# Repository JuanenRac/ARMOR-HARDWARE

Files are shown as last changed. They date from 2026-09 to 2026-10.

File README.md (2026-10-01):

<p align="center">
  ARMOR-HARDWARE banner
</p>

# 🧱 ARMOR-HARDWARE

<p align="center">
  🇺🇸 <b>English</b> |
  <a href="README_spa.md">🇪🇸 Español</a> |
  <a href="README_fra.md">🇫🇷 Français</a> |
  <a href="README_ita.md">🇮🇹 Italiano</a> |
  <a href="README_deu.md">🇩🇪 Deutsch</a> |
  <a href="README_zho.md">🇨🇳 简体中文</a> |
  <a href="README_jpn.md">🇯🇵 日本語</a>
</p>

### Enclosures, electronics and the bench acceptance matrix

<p align="center">
  
  
  
  
</p>

---

**Honesty check - what runs today:** The enclosure is a **printable mechanical starting point, not an IP, RF or thermal rating.** Nothing has been measured on a prototype; every row of the [bench acceptance matrix](docs/BENCH_ACCEPTANCE.md) is *not tested*.

---

## 🎯 Overview

* **The real design is `CAD/CARCASA_SENSORES.scad`** (with STL, 3MF and AMF exports): a 90-degree corner base with a visor, roof and floor, retaining steps, a sliding 2 mm front cover and side flaps, all driven by named parameters. `scad/node_enclosure.scad` is only a placeholder box.
* **Reserved volumes** for three radar modules, the ESP32-S3-ETH-PoE board, the sensor window, a cable gland, the PoE magnetics and the PTC heater. No metallic, conductive or carbon-loaded material in front of a 24 GHz aperture without measured attenuation.
* **Bench acceptance matrix:** the radio, environment, power, network and camera checks with a method and a proposed pass criterion each, and a camera compatibility table to fill in.
* Before fabrication, record exact board outlines, connectors, screw positions, antenna keep-outs, the thermal path and the ingress target ([design inputs](docs/DESIGN_INPUTS.md)).

## 📂 Repository Structure

```text
ARMOR-HARDWARE/
├── CAD/     CARCASA_SENSORES.scad (+ stl, 3mf, amf)
├── scad/    node_enclosure.scad (placeholder)
├── EDA/     KiCad (empty)
└── docs/    DESIGN_INPUTS, VALIDATION, BENCH_ACCEPTANCE
```

## 🛠️ Development Environment

```powershell
openscad -o build/CARCASA_SENSORES.stl CAD/CARCASA_SENSORES.scad
```

See the [validation boundary](docs/VALIDATION.md). The intended hardware licence is CERN-OHL-S-2.0; add its full text before releasing the designs.

## 🔗 Related Projects

**A.R.M.O.R.** (Autonomous Radar & Multimodal Observation Range) is a perimeter-security system made of independent repositories. Each one has its own version, its own tests and its own README; this is the family:

* **[ARMOR-COMMON](https://github.com/JuanenRac/ARMOR-COMMON)** - Message contracts, validators, conformance vectors and generated types
* **[ARMOR-RADAR](https://github.com/JuanenRac/ARMOR-RADAR)** - Field-node firmware for ESP32-S3 with three radars and its own web panel
* **[ARMOR-SOLAR](https://github.com/JuanenRac/ARMOR-SOLAR)** - Solar inverter and battery protocols and the messages of a gateway node
* **[ARMOR-ELECTRICAL](https://github.com/JuanenRac/ARMOR-ELECTRICAL)** - Electrical node: meters, the message of the network's readings and the rules for switching
* **[ARMOR-HMI](https://github.com/JuanenRac/ARMOR-HMI)** - Touch panel: the state of the system on a wall screen, arming and acknowledging, and the home of the voice assistant
* **[ARMOR-NETWORK](https://github.com/JuanenRac/ARMOR-NETWORK)** - The local network: its devices, the internet and what changes
* **[ARMOR-SERVER](https://github.com/JuanenRac/ARMOR-SERVER)** - Central coordinator: telemetry, alarms, devices, solar readings and cameras
* **[ARMOR-STUDIO](https://github.com/JuanenRac/ARMOR-STUDIO)** - Web console: cameras, radar, alarms, solar energy and the 2D/3D site designer
* **[ARMOR-ANDROID-CONTROL](https://github.com/JuanenRac/ARMOR-ANDROID-CONTROL)** - Android operator client with a live 2D/3D radar
* **[ARMOR-SERVER-AI](https://github.com/JuanenRac/ARMOR-SERVER-AI)** - Visual inference policy that explains its decisions and never actuates
* **[ARMOR-VOICE-AI](https://github.com/JuanenRac/ARMOR-VOICE-AI)** - Offline voice intents with a confirmation that cannot be forged
* **ARMOR-HARDWARE** (this repository) - Enclosures, electronics and the bench acceptance matrix
* **[ARMOR-DEVOPS](https://github.com/JuanenRac/ARMOR-DEVOPS)** - Deployment, the CM5 test bench, backup and TLS
* **[ARMOR-SIMULATOR](https://github.com/JuanenRac/ARMOR-SIMULATOR)** - Offline telemetry simulator with repeatable faults
* **[ARMOR-UPDATER](https://github.com/JuanenRac/ARMOR-UPDATER)** - Detects, installs and updates the ecosystem's own repositories
* **[ARMOR-DOCS](https://github.com/JuanenRac/ARMOR-DOCS)** - Architecture, security baseline and the capability matrix

## 📚 Documentation & Community

Where to read more:

* [Capability matrix: what is proven and what is not](https://github.com/JuanenRac/ARMOR-DOCS/blob/main/docs/CAPABILITY_MATRIX.md)
* [Project catalogue: versions and how the repositories depend on each other](https://github.com/JuanenRac/ARMOR-DOCS/blob/main/docs/PROJECT_CATALOG.md)
* [Changelog of this repository](CHANGELOG.md)
* [License (GPL-3.0-or-later)](LICENSE)
* Questions, ideas and reports: electrohobby3d@gmail.com

## 👤 AUTHOR

**JuanenRac (Electro Hobby 3D)** · electrohobby3d@gmail.com

## 📜 LICENSE

GPL-3.0-or-later - see [LICENSE](LICENSE).

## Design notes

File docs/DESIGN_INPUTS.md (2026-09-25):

# Design inputs and open decisions

The outdoor node design must reserve independent volumes for three radar modules,
the ESP32-S3-ETH-PoE controller, sensor window, cable gland, PoE magnetics and
PTC heater. Do not place a metallic, conductive or carbon-loaded material in
front of a 24 GHz radar aperture without measured attenuation data.

Before fabrication, record exact board outlines, connectors, screw locations,
antenna keep-outs, thermal path and ingress target. The current CAD remains a
mechanical concept, not manufacturing evidence.

## The HLK-LD2450, from its manual

Facts taken from the Hi-Link *HLK-LD2450 Instruction manual* V1.00 (2023-05-10); they are the
manufacturer's statements, not measurements of this project.

| Item | Manual |
|---|---|
| Size | 15 mm x 44 mm, pin or socket interface (UART, 5 V, GND) |
| Supply | 5 V, source able to give more than 200 mA; 120 mA average, so three modules draw about 0.6 W |
| Logic | 3.3 V I/O, UART 256000 baud, 8N1 |
| Range and angle | 6 m maximum, azimuth plus or minus 60 degrees, pitch plus or minus 35 degrees, three targets, 10 Hz |
| Band | 24 GHz to 24.25 GHz, FMCW |
| Ambient temperature | -40 to 85 degrees C |
| Mounting | Wall mounting, height 1.5 m to 2 m recommended; antenna facing the area, open and unobstructed; fixed firmly (shaking degrades detection) |
| Back of the module | The antenna's back lobe can see movement behind the module; a metal shield or back plate reduces it |
| Several 24 GHz radars | Do not point them at each other; keep them as far apart as possible |
| Cover | No metal or conductive material or coating; smooth, flat and of uniform thickness, parallel to the antenna |

### Cover guidance in the manual, applied to this enclosure

* Distance from the antenna to the inner face of the cover: 1 or 1.5 wavelengths, that is **12.4 mm or 18.6 mm** at
  24.125 GHz, tolerance plus or minus 1.2 mm.
* Thickness: about half a wavelength **in the material** (plus or minus 20 %); for an ABS-like plastic
  (relative permittivity about 2.5) that is about **3.9 mm**. If that is not possible, use a low-permittivity
  material at **one eighth of a wavelength or thinner**, about 1 mm for that same plastic.
* The CAD front cover is `tapa_grosor = 2` mm. For a permittivity near 2.5 that is close to a *quarter* of a
  wavelength in the material, which is neither of the two recommended cases and, for a plain slab, where
  reflection is greatest. This is arithmetic from the manual's formula, not a measurement, and the real
  permittivity of the printed ASA or PETG is unknown: measure it (see [BENCH_ACCEPTANCE](BENCH_ACCEPTANCE.md))
  before printing the final cover, and consider about 1 mm or about 3.9 mm.
* Check the antenna-to-cover distance in the CAD against 12.4 mm or 18.6 mm; it has not been checked.

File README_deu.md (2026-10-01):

<p align="center">
  ARMOR-HARDWARE banner
</p>

# 🧱 ARMOR-HARDWARE

<p align="center">
  <a href="README.md">🇺🇸 English</a> |
  <a href="README_spa.md">🇪🇸 Español</a> |
  <a href="README_fra.md">🇫🇷 Français</a> |
  <a href="README_ita.md">🇮🇹 Italiano</a> |
  🇩🇪 <b>Deutsch</b> |
  <a href="README_zho.md">🇨🇳 简体中文</a> |
  <a href="README_jpn.md">🇯🇵 日本語</a>
</p>

### Gehäuse, Elektronik und die Abnahmematrix am Prüfstand

<p align="center">
  
  
  
  
</p>

---

**Ehrlichkeitsprüfung - was heute läuft:** Das Gehäuse ist ein **druckbarer mechanischer Ausgangspunkt, keine IP-, HF- oder Thermik-Zertifizierung.** Nichts wurde an einem Prototyp gemessen; jede Zeile der [Abnahmematrix am Prüfstand](docs/BENCH_ACCEPTANCE.md) ist *nicht getestet*.

---

## 🎯 Überblick

* **Das echte Design ist `CAD/CARCASA_SENSORES.scad`** (mit STL-, 3MF- und AMF-Exporten): eine 90-Grad-Eckbasis mit Blende, Dach und Boden, Halte-Stufen, einer verschiebbaren 2-mm-Frontabdeckung und Seitenklappen, alles über benannte Parameter gesteuert. `scad/node_enclosure.scad` ist nur eine Platzhalterbox.
* **Reservierte Volumen** für drei Radarmodule, die Platine ESP32-S3-ETH-PoE, das Sensorfenster, eine Kabelverschraubung, die PoE-Magnetics und die PTC-Heizung. Kein metallisches, leitfähiges oder kohlenstoffgefülltes Material vor einer 24-GHz-Öffnung ohne gemessene Dämpfung.
* **Abnahmematrix am Prüfstand:** die Prüfungen für Funk, Umgebung, Strom, Netz und Kamera, jeweils mit Methode und vorgeschlagenem Bestehenskriterium, und eine auszufüllende Kamera-Kompatibilitätstabelle.
* Vor der Fertigung genaue Platinenumrisse, Steckverbinder, Schraubenpositionen, Antennen-Freihaltezonen, den Wärmepfad und das Schutzziel festhalten ([Entwurfseingaben](docs/DESIGN_INPUTS.md)).

## 📂 Struktur des Repositorys

```text
ARMOR-HARDWARE/
├── CAD/     CARCASA_SENSORES.scad (+ stl, 3mf, amf)
├── scad/    node_enclosure.scad (placeholder)
├── EDA/     KiCad (empty)
└── docs/    DESIGN_INPUTS, VALIDATION, BENCH_ACCEPTANCE
```

## 🛠️ Entwicklungsumgebung

```powershell
openscad -o build/CARCASA_SENSORES.stl CAD/CARCASA_SENSORES.scad
```

Siehe die [Validierungsgrenze](docs/VALIDATION.md). Die vorgesehene Hardwarelizenz ist CERN-OHL-S-2.0; den vollen Text vor der Veröffentlichung der Entwürfe hinzufügen.

## 🔗 Verwandte Projekte

**A.R.M.O.R.** (Autonomous Radar & Multimodal Observation Range) ist ein Perimeter-Sicherheitssystem aus unabhängigen Repositorys. Jedes hat eine eigene Version, eigene Tests und ein eigenes README; hier ist die Familie:

* **[ARMOR-COMMON](https://github.com/JuanenRac/ARMOR-COMMON)** - Nachrichtenverträge, Validierer, Konformitätsvektoren und generierte Typen
* **[ARMOR-RADAR](https://github.com/JuanenRac/ARMOR-RADAR)** - Feldknoten-Firmware für ESP32-S3 mit drei Radaren und eigenem Web-Panel
* **[ARMOR-SOLAR](https://github.com/JuanenRac/ARMOR-SOLAR)** - Protokolle für Solar-Wechselrichter und -Batterien und die Nachrichten eines Gateway-Knotens
* **[ARMOR-ELECTRICAL](https://github.com/JuanenRac/ARMOR-ELECTRICAL)** - Elektroknoten: Zähler, die Nachricht der Netzmesswerte und die Regeln fürs Schalten
* **[ARMOR-HMI](https://github.com/JuanenRac/ARMOR-HMI)** - Touch-Panel: der Systemzustand auf einem Wandbildschirm, Scharf- und Quittieren sowie das Zuhause des Sprachassistenten
* **[ARMOR-NETWORK](https://github.com/JuanenRac/ARMOR-NETWORK)** - Das lokale Netzwerk: seine Geräte, das Internet und was sich ändert
* **[ARMOR-SERVER](https://github.com/JuanenRac/ARMOR-SERVER)** - Zentraler Koordinator: Telemetrie, Alarme, Geräte, Solarmesswerte und Kameras
* **[ARMOR-STUDIO](https://github.com/JuanenRac/ARMOR-STUDIO)** - Web-Konsole: Kameras, Radar, Alarme, Solarenergie und 2D/3D-Standortdesigner
* **[ARMOR-ANDROID-CONTROL](https://github.com/JuanenRac/ARMOR-ANDROID-CONTROL)** - Android-Bedienclient mit Live-Radar in 2D/3D
* **[ARMOR-SERVER-AI](https://github.com/JuanenRac/ARMOR-SERVER-AI)** - Visuelle Inferenzrichtlinie, die ihre Entscheidungen erklärt und nie handelt
* **[ARMOR-VOICE-AI](https://github.com/JuanenRac/ARMOR-VOICE-AI)** - Offline-Sprachabsichten mit einer nicht fälschbaren Bestätigung
* **ARMOR-HARDWARE** (dieses Repository) - Gehäuse, Elektronik und die Abnahmematrix am Prüfstand
* **[ARMOR-DEVOPS](https://github.com/JuanenRac/ARMOR-DEVOPS)** - Bereitstellung, CM5-Prüfstand, Backup und TLS
* **[ARMOR-SIMULATOR](https://github.com/JuanenRac/ARMOR-SIMULATOR)** - Offline-Telemetriesimulator mit wiederholbaren Fehlern
* **[ARMOR-UPDATER](https://github.com/JuanenRac/ARMOR-UPDATER)** - Erkennt, installiert und aktualisiert die eigenen Repositories des Ökosystems
* **[ARMOR-DOCS](https://github.com/JuanenRac/ARMOR-DOCS)** - Architektur, Sicherheitsgrundlage und die Fähigkeitsmatrix

## 📚 Dokumentation und Community

Hier gibt es mehr zu lesen:

* [Fähigkeitsmatrix: was belegt ist und was nicht](https://github.com/JuanenRac/ARMOR-DOCS/blob/main/docs/CAPABILITY_MATRIX.md)
* [Projektkatalog: Versionen und wie die Repositorys voneinander abhängen](https://github.com/JuanenRac/ARMOR-DOCS/blob/main/docs/PROJECT_CATALOG.md)
* [Änderungsverlauf dieses Repositorys](CHANGELOG.md)
* [Lizenz (GPL-3.0-or-later)](LICENSE)
* Fragen, Ideen und Meldungen: electrohobby3d@gmail.com

## 👤 AUTOR

**JuanenRac (Electro Hobby 3D)** · electrohobby3d@gmail.com

## 📜 LIZENZ

GPL-3.0-or-later - siehe [LICENSE](LICENSE).

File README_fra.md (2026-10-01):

<p align="center">
  ARMOR-HARDWARE banner
</p>

# 🧱 ARMOR-HARDWARE

<p align="center">
  <a href="README.md">🇺🇸 English</a> |
  <a href="README_spa.md">🇪🇸 Español</a> |
  🇫🇷 <b>Français</b> |
  <a href="README_ita.md">🇮🇹 Italiano</a> |
  <a href="README_deu.md">🇩🇪 Deutsch</a> |
  <a href="README_zho.md">🇨🇳 简体中文</a> |
  <a href="README_jpn.md">🇯🇵 日本語</a>
</p>

### Boîtiers, électronique et matrice d'acceptation sur banc

<p align="center">
  
  
  
  
</p>

---

**Vérification d'honnêteté - ce qui fonctionne aujourd'hui:** Le boîtier est un **point de départ mécanique imprimable, pas une certification IP, RF ou thermique.** Rien n'a été mesuré sur un prototype ; chaque ligne de la [matrice d'acceptation sur banc](docs/BENCH_ACCEPTANCE.md) est *non testée*.

---

## 🎯 Présentation

* **Le vrai design est `CAD/CARCASA_SENSORES.scad`** (avec exports STL, 3MF et AMF) : une base d'angle à 90 degrés avec visière, toit et fond, des gradins de retenue, un couvercle frontal coulissant de 2 mm et des rabats latéraux, le tout piloté par des paramètres nommés. `scad/node_enclosure.scad` n'est qu'une boîte provisoire.
* **Volumes réservés** pour trois modules radar, la carte ESP32-S3-ETH-PoE, la fenêtre du capteur, un presse-étoupe, les magnétiques PoE et le réchauffeur PTC. Aucun matériau métallique, conducteur ou chargé de carbone devant une ouverture 24 GHz sans atténuation mesurée.
* **Matrice d'acceptation sur banc :** les contrôles radio, environnement, alimentation, réseau et caméra, chacun avec une méthode et un critère de réussite proposé, et un tableau de compatibilité des caméras à remplir.
* Avant la fabrication, consigner les contours exacts des cartes, les connecteurs, la position des vis, les zones d'exclusion d'antenne, le chemin thermique et l'objectif d'étanchéité ([données de conception](docs/DESIGN_INPUTS.md)).

## 📂 Structure du dépôt

```text
ARMOR-HARDWARE/
├── CAD/     CARCASA_SENSORES.scad (+ stl, 3mf, amf)
├── scad/    node_enclosure.scad (placeholder)
├── EDA/     KiCad (empty)
└── docs/    DESIGN_INPUTS, VALIDATION, BENCH_ACCEPTANCE
```

## 🛠️ Environnement de développement

```powershell
openscad -o build/CARCASA_SENSORES.stl CAD/CARCASA_SENSORES.scad
```

Voir la [frontière de validation](docs/VALIDATION.md). La licence matérielle prévue est CERN-OHL-S-2.0 ; ajoutez son texte complet avant de publier les designs.

## 🔗 Projets liés

**A.R.M.O.R.** (Autonomous Radar & Multimodal Observation Range) est un système de sécurité périmétrique composé de dépôts indépendants. Chacun a sa propre version, ses propres tests et son propre README ; voici la famille :

* **[ARMOR-COMMON](https://github.com/JuanenRac/ARMOR-COMMON)** - Contrats de messages, validateurs, vecteurs de conformité et types générés
* **[ARMOR-RADAR](https://github.com/JuanenRac/ARMOR-RADAR)** - Firmware du nœud de terrain pour ESP32-S3 avec trois radars et son propre panneau web
* **[ARMOR-SOLAR](https://github.com/JuanenRac/ARMOR-SOLAR)** - Protocoles des onduleurs et batteries solaires et messages d'un nœud passerelle
* **[ARMOR-ELECTRICAL](https://github.com/JuanenRac/ARMOR-ELECTRICAL)** - Nœud électrique : compteurs, le message des mesures du réseau et les règles de commutation
* **[ARMOR-HMI](https://github.com/JuanenRac/ARMOR-HMI)** - Panneau tactile : l'état du système sur un écran mural, armer et acquitter, et la maison de l'assistant vocal
* **[ARMOR-NETWORK](https://github.com/JuanenRac/ARMOR-NETWORK)** - Le réseau local : ses appareils, internet et ce qui change
* **[ARMOR-SERVER](https://github.com/JuanenRac/ARMOR-SERVER)** - Coordinateur central : télémétrie, alarmes, appareils, relevés solaires et caméras
* **[ARMOR-STUDIO](https://github.com/JuanenRac/ARMOR-STUDIO)** - Console web : caméras, radar, alarmes, énergie solaire et concepteur de site 2D/3D
* **[ARMOR-ANDROID-CONTROL](https://github.com/JuanenRac/ARMOR-ANDROID-CONTROL)** - Client Android de l'opérateur avec radar 2D/3D en direct
* **[ARMOR-SERVER-AI](https://github.com/JuanenRac/ARMOR-SERVER-AI)** - Politique d'inférence visuelle qui explique ses décisions et n'agit jamais
* **[ARMOR-VOICE-AI](https://github.com/JuanenRac/ARMOR-VOICE-AI)** - Intentions vocales hors ligne avec une confirmation impossible à falsifier
* **ARMOR-HARDWARE** (ce dépôt) - Boîtiers, électronique et matrice d'acceptation sur banc
* **[ARMOR-DEVOPS](https://github.com/JuanenRac/ARMOR-DEVOPS)** - Déploiement, banc d'essai CM5, sauvegarde et TLS
* **[ARMOR-SIMULATOR](https://github.com/JuanenRac/ARMOR-SIMULATOR)** - Simulateur de télémétrie hors ligne avec des pannes reproductibles
* **[ARMOR-UPDATER](https://github.com/JuanenRac/ARMOR-UPDATER)** - Détecte, installe et met à jour les propres dépôts de l'écosystème
* **[ARMOR-DOCS](https://github.com/JuanenRac/ARMOR-DOCS)** - Architecture, base de sécurité et matrice des capacités

## 📚 Documentation et communauté

Pour en savoir plus :

* [Matrice des capacités : ce qui est prouvé et ce qui ne l'est pas](https://github.com/JuanenRac/ARMOR-DOCS/blob/main/docs/CAPABILITY_MATRIX.md)
* [Catalogue des projets : versions et dépendances entre les dépôts](https://github.com/JuanenRac/ARMOR-DOCS/blob/main/docs/PROJECT_CATALOG.md)
* [Historique des modifications de ce dépôt](CHANGELOG.md)
* [Licence (GPL-3.0-or-later)](LICENSE)
* Questions, idées et rapports : electrohobby3d@gmail.com

## 👤 AUTEUR

**JuanenRac (Electro Hobby 3D)** · electrohobby3d@gmail.com

## 📜 LICENCE

GPL-3.0-or-later - voir [LICENSE](LICENSE).

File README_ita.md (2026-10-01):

<p align="center">
  ARMOR-HARDWARE banner
</p>

# 🧱 ARMOR-HARDWARE

<p align="center">
  <a href="README.md">🇺🇸 English</a> |
  <a href="README_spa.md">🇪🇸 Español</a> |
  <a href="README_fra.md">🇫🇷 Français</a> |
  🇮🇹 <b>Italiano</b> |
  <a href="README_deu.md">🇩🇪 Deutsch</a> |
  <a href="README_zho.md">🇨🇳 简体中文</a> |
  <a href="README_jpn.md">🇯🇵 日本語</a>
</p>

### Contenitori, elettronica e matrice di accettazione da banco

<p align="center">
  
  
  
  
</p>

---

**Controllo di onestà - cosa funziona oggi:** Il contenitore è un **punto di partenza meccanico stampabile, non una certificazione IP, RF o termica.** Nulla è stato misurato su un prototipo; ogni riga della [matrice di accettazione da banco](docs/BENCH_ACCEPTANCE.md) è *non testata*.

---

## 🎯 Panoramica

* **Il vero progetto è `CAD/CARCASA_SENSORES.scad`** (con esportazioni STL, 3MF e AMF): una base d'angolo a 90 gradi con visiera, tetto e fondo, gradini di ritegno, un coperchio frontale scorrevole da 2 mm e alette laterali, tutto guidato da parametri con nome. `scad/node_enclosure.scad` è solo una scatola provvisoria.
* **Volumi riservati** per tre moduli radar, la scheda ESP32-S3-ETH-PoE, la finestra del sensore, un passacavo, la magnetica PoE e il riscaldatore PTC. Nessun materiale metallico, conduttivo o caricato di carbonio davanti a un'apertura a 24 GHz senza attenuazione misurata.
* **Matrice di accettazione da banco:** i controlli di radio, ambiente, alimentazione, rete e telecamera, ciascuno con un metodo e un criterio di superamento proposto, e una tabella di compatibilità delle telecamere da compilare.
* Prima della fabbricazione, registrare i contorni esatti delle schede, i connettori, la posizione delle viti, le aree di esclusione delle antenne, il percorso termico e l'obiettivo di tenuta ([dati di progetto](docs/DESIGN_INPUTS.md)).

## 📂 Struttura del repository

```text
ARMOR-HARDWARE/
├── CAD/     CARCASA_SENSORES.scad (+ stl, 3mf, amf)
├── scad/    node_enclosure.scad (placeholder)
├── EDA/     KiCad (empty)
└── docs/    DESIGN_INPUTS, VALIDATION, BENCH_ACCEPTANCE
```

## 🛠️ Ambiente di sviluppo

```powershell
openscad -o build/CARCASA_SENSORES.stl CAD/CARCASA_SENSORES.scad
```

Vedi il [confine di validazione](docs/VALIDATION.md). La licenza hardware prevista è CERN-OHL-S-2.0; aggiungi il testo completo prima di pubblicare i progetti.

## 🔗 Progetti correlati

**A.R.M.O.R.** (Autonomous Radar & Multimodal Observation Range) è un sistema di sicurezza perimetrale fatto di repository indipendenti. Ognuno ha la propria versione, i propri test e il proprio README; ecco la famiglia:

* **[ARMOR-COMMON](https://github.com/JuanenRac/ARMOR-COMMON)** - Contratti dei messaggi, validatori, vettori di conformità e tipi generati
* **[ARMOR-RADAR](https://github.com/JuanenRac/ARMOR-RADAR)** - Firmware del nodo di campo per ESP32-S3 con tre radar e un proprio pannello web
* **[ARMOR-SOLAR](https://github.com/JuanenRac/ARMOR-SOLAR)** - Protocolli di inverter e batterie solari e messaggi di un nodo gateway
* **[ARMOR-ELECTRICAL](https://github.com/JuanenRac/ARMOR-ELECTRICAL)** - Nodo elettrico: contatori, il messaggio delle letture della rete e le regole di manovra
* **[ARMOR-HMI](https://github.com/JuanenRac/ARMOR-HMI)** - Pannello touch: lo stato del sistema su uno schermo a parete, attivare e riconoscere gli allarmi, e la casa dell'assistente vocale
* **[ARMOR-NETWORK](https://github.com/JuanenRac/ARMOR-NETWORK)** - La rete locale: i suoi dispositivi, internet e ciò che cambia
* **[ARMOR-SERVER](https://github.com/JuanenRac/ARMOR-SERVER)** - Coordinatore centrale: telemetria, allarmi, dispositivi, letture solari e telecamere
* **[ARMOR-STUDIO](https://github.com/JuanenRac/ARMOR-STUDIO)** - Console web: telecamere, radar, allarmi, energia solare e progettista del sito 2D/3D
* **[ARMOR-ANDROID-CONTROL](https://github.com/JuanenRac/ARMOR-ANDROID-CONTROL)** - Client Android dell'operatore con radar 2D/3D in tempo reale
* **[ARMOR-SERVER-AI](https://github.com/JuanenRac/ARMOR-SERVER-AI)** - Politica di inferenza visiva che spiega le sue decisioni e non agisce mai
* **[ARMOR-VOICE-AI](https://github.com/JuanenRac/ARMOR-VOICE-AI)** - Intenti vocali offline con una conferma impossibile da falsificare
* **ARMOR-HARDWARE** (questo repository) - Contenitori, elettronica e matrice di accettazione da banco
* **[ARMOR-DEVOPS](https://github.com/JuanenRac/ARMOR-DEVOPS)** - Distribuzione, banco di prova CM5, backup e TLS
* **[ARMOR-SIMULATOR](https://github.com/JuanenRac/ARMOR-SIMULATOR)** - Simulatore di telemetria offline con guasti ripetibili
* **[ARMOR-UPDATER](https://github.com/JuanenRac/ARMOR-UPDATER)** - Rileva, installa e aggiorna i repository stessi dell'ecosistema
* **[ARMOR-DOCS](https://github.com/JuanenRac/ARMOR-DOCS)** - Architettura, base di sicurezza e matrice delle capacità

## 📚 Documentazione e comunità

Dove leggere di più:

* [Matrice delle capacità: cosa è provato e cosa no](https://github.com/JuanenRac/ARMOR-DOCS/blob/main/docs/CAPABILITY_MATRIX.md)
* [Catalogo dei progetti: versioni e dipendenze tra i repository](https://github.com/JuanenRac/ARMOR-DOCS/blob/main/docs/PROJECT_CATALOG.md)
* [Cronologia delle modifiche di questo repository](CHANGELOG.md)
* [Licenza (GPL-3.0-or-later)](LICENSE)
* Domande, idee e segnalazioni: electrohobby3d@gmail.com

## 👤 AUTORE

**JuanenRac (Electro Hobby 3D)** · electrohobby3d@gmail.com

## 📜 LICENZA

GPL-3.0-or-later - vedi [LICENSE](LICENSE).

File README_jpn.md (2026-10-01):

<p align="center">
  ARMOR-HARDWARE banner
</p>

# 🧱 ARMOR-HARDWARE

<p align="center">
  <a href="README.md">🇺🇸 English</a> |
  <a href="README_spa.md">🇪🇸 Español</a> |
  <a href="README_fra.md">🇫🇷 Français</a> |
  <a href="README_ita.md">🇮🇹 Italiano</a> |
  <a href="README_deu.md">🇩🇪 Deutsch</a> |
  <a href="README_zho.md">🇨🇳 简体中文</a> |
  🇯🇵 <b>日本語</b>
</p>

### 筐体、電子部品、ベンチ受け入れマトリクス

<p align="center">
  
  
  
  
</p>

---

**正直さのチェック - 今日動いているもの:** 筐体は**印刷可能な機械的な出発点であり、IP、RF、熱の認証ではありません。** 試作品では何も測定していません。[ベンチ受け入れマトリクス](docs/BENCH_ACCEPTANCE.md)のすべての行は*未テスト*です。

---

## 🎯 概要

* **本当の設計は `CAD/CARCASA_SENSORES.scad`**（STL、3MF、AMF のエクスポート付き）：ひさし、屋根、床を備えた 90 度のコーナーベース、保持用の段、2 mm のスライド式フロントカバーとサイドフラップ。すべて名前付きパラメーターで制御されます。`scad/node_enclosure.scad` は仮の箱にすぎません。
* **予約された空間：** レーダーモジュール 3 基、ESP32-S3-ETH-PoE ボード、センサー窓、ケーブルグランド、PoE マグネティクス、PTC ヒーター。減衰を測定していない限り、24 GHz の開口の前に金属、導電性、カーボン入りの材料を置かないこと。
* **ベンチ受け入れマトリクス：** 無線、環境、電源、ネットワーク、カメラの各チェックに、方法と提案する合格基準を付け、記入するカメラ互換性表も用意しています。
* 製造の前に、ボードの正確な外形、コネクター、ネジ位置、アンテナの禁止領域、熱経路、防塵防水の目標を記録すること（[設計入力](docs/DESIGN_INPUTS.md)）。

## 📂 リポジトリの構成

```text
ARMOR-HARDWARE/
├── CAD/     CARCASA_SENSORES.scad (+ stl, 3mf, amf)
├── scad/    node_enclosure.scad (placeholder)
├── EDA/     KiCad (empty)
└── docs/    DESIGN_INPUTS, VALIDATION, BENCH_ACCEPTANCE
```

## 🛠️ 開発環境

```powershell
openscad -o build/CARCASA_SENSORES.stl CAD/CARCASA_SENSORES.scad
```

[検証の境界](docs/VALIDATION.md)を参照。想定するハードウェアライセンスは CERN-OHL-S-2.0 です。設計を公開する前にその全文を追加してください。

## 🔗 関連プロジェクト

**A.R.M.O.R.**（Autonomous Radar & Multimodal Observation Range）は、独立したリポジトリで構成される周辺警備システムです。それぞれに独自のバージョン、テスト、README があります。ファミリーは次のとおりです：

* **[ARMOR-COMMON](https://github.com/JuanenRac/ARMOR-COMMON)** - メッセージ契約、検証器、適合性ベクトル、生成された型
* **[ARMOR-RADAR](https://github.com/JuanenRac/ARMOR-RADAR)** - ESP32-S3 用フィールドノードのファームウェア。レーダー 3 基と独自の Web パネル付き
* **[ARMOR-SOLAR](https://github.com/JuanenRac/ARMOR-SOLAR)** - 太陽光インバーターとバッテリーのプロトコル、およびゲートウェイノードのメッセージ
* **[ARMOR-ELECTRICAL](https://github.com/JuanenRac/ARMOR-ELECTRICAL)** - 電気ノード：電力量計、電力網の計測メッセージ、開閉のルール
* **[ARMOR-HMI](https://github.com/JuanenRac/ARMOR-HMI)** - タッチパネル：壁面ディスプレイでのシステム状態表示、警戒・確認操作、音声アシスタントの拠点
* **[ARMOR-NETWORK](https://github.com/JuanenRac/ARMOR-NETWORK)** - ローカルネットワーク：機器、インターネット、そして変化
* **[ARMOR-SERVER](https://github.com/JuanenRac/ARMOR-SERVER)** - 中央コーディネーター：テレメトリ、アラーム、デバイス、太陽光の測定値、カメラ
* **[ARMOR-STUDIO](https://github.com/JuanenRac/ARMOR-STUDIO)** - Web コンソール：カメラ、レーダー、アラーム、太陽光発電、2D/3D サイト設計
* **[ARMOR-ANDROID-CONTROL](https://github.com/JuanenRac/ARMOR-ANDROID-CONTROL)** - リアルタイム 2D/3D レーダー付きの Android オペレータークライアント
* **[ARMOR-SERVER-AI](https://github.com/JuanenRac/ARMOR-SERVER-AI)** - 判断を説明し、決して動作しない視覚推論ポリシー
* **[ARMOR-VOICE-AI](https://github.com/JuanenRac/ARMOR-VOICE-AI)** - 偽造できない確認を備えたオフライン音声インテント
* **ARMOR-HARDWARE** (このリポジトリ) - 筐体、電子部品、ベンチ受け入れマトリクス
* **[ARMOR-DEVOPS](https://github.com/JuanenRac/ARMOR-DEVOPS)** - デプロイ、CM5 テストベンチ、バックアップ、TLS
* **[ARMOR-SIMULATOR](https://github.com/JuanenRac/ARMOR-SIMULATOR)** - 再現可能な故障を備えたオフラインのテレメトリシミュレーター
* **[ARMOR-UPDATER](https://github.com/JuanenRac/ARMOR-UPDATER)** - エコシステム自身のリポジトリを検出し、インストールし、更新する
* **[ARMOR-DOCS](https://github.com/JuanenRac/ARMOR-DOCS)** - アーキテクチャ、セキュリティ基準、機能マトリクス

## 📚 ドキュメントとコミュニティ

詳しくは：

* [機能マトリクス：実証済みのものとそうでないもの](https://github.com/JuanenRac/ARMOR-DOCS/blob/main/docs/CAPABILITY_MATRIX.md)
* [プロジェクト一覧：バージョンとリポジトリ間の依存関係](https://github.com/JuanenRac/ARMOR-DOCS/blob/main/docs/PROJECT_CATALOG.md)
* [このリポジトリの変更履歴](CHANGELOG.md)
* [ライセンス（GPL-3.0-or-later）](LICENSE)
* 質問・提案・報告：electrohobby3d@gmail.com

## 👤 作者

**JuanenRac (Electro Hobby 3D)** · electrohobby3d@gmail.com

## 📜 ライセンス

GPL-3.0-or-later - [LICENSE](LICENSE) を参照。

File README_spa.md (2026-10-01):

<p align="center">
  ARMOR-HARDWARE banner
</p>

# 🧱 ARMOR-HARDWARE

<p align="center">
  <a href="README.md">🇺🇸 English</a> |
  🇪🇸 <b>Español</b> |
  <a href="README_fra.md">🇫🇷 Français</a> |
  <a href="README_ita.md">🇮🇹 Italiano</a> |
  <a href="README_deu.md">🇩🇪 Deutsch</a> |
  <a href="README_zho.md">🇨🇳 简体中文</a> |
  <a href="README_jpn.md">🇯🇵 日本語</a>
</p>

### Carcasas, electrónica y la matriz de aceptación de banco

<p align="center">
  
  
  
  
</p>

---

**Comprobación de honestidad - qué funciona hoy:** La carcasa es un **punto de partida mecánico imprimible, no una clasificación IP, RF ni térmica.** No se ha medido nada en un prototipo; cada fila de la [matriz de aceptación de banco](docs/BENCH_ACCEPTANCE.md) está *sin probar*.

---

## 🎯 Descripción general

* **El diseño real es `CAD/CARCASA_SENSORES.scad`** (con exportaciones STL, 3MF y AMF): una base de esquina de 90 grados con visera, techo y suelo, escalones de retención, una tapa frontal deslizante de 2 mm y solapas laterales, todo gobernado por parámetros con nombre. `scad/node_enclosure.scad` es solo una caja de ejemplo.
* **Volúmenes reservados** para tres módulos de radar, la placa ESP32-S3-ETH-PoE, la ventana del sensor, un prensaestopas, la magnética PoE y el calefactor PTC. Ningún material metálico, conductor o cargado de carbono delante de una apertura de 24 GHz sin atenuación medida.
* **Matriz de aceptación de banco:** las comprobaciones de radio, entorno, alimentación, red y cámaras con un método y un criterio propuesto cada una, y una tabla de compatibilidad de cámaras por rellenar.
* Antes de fabricar, registrar contornos exactos de placas, conectores, posición de tornillos, zonas libres de antena, el camino térmico y el objetivo de estanqueidad ([entradas de diseño](docs/DESIGN_INPUTS.md)).

## 📂 Estructura del repositorio

```text
ARMOR-HARDWARE/
├── CAD/     CARCASA_SENSORES.scad (+ stl, 3mf, amf)
├── scad/    node_enclosure.scad (ejemplo)
├── EDA/     KiCad (vacío)
└── docs/    DESIGN_INPUTS, VALIDATION, BENCH_ACCEPTANCE
```

## 🛠️ Entorno de desarrollo

```powershell
openscad -o build/CARCASA_SENSORES.stl CAD/CARCASA_SENSORES.scad
```

Véase el [límite de validación](docs/VALIDATION.md). La licencia de hardware prevista es CERN-OHL-S-2.0; añade su texto completo antes de publicar los diseños.

## 🔗 Proyectos relacionados

**A.R.M.O.R.** (Autonomous Radar & Multimodal Observation Range) es un sistema de seguridad perimetral hecho de repositorios independientes. Cada uno tiene su propia versión, sus propias pruebas y su propio README; esta es la familia:

* **[ARMOR-COMMON](https://github.com/JuanenRac/ARMOR-COMMON)** - Contratos de mensajes, validadores, vectores de conformidad y tipos generados
* **[ARMOR-RADAR](https://github.com/JuanenRac/ARMOR-RADAR)** - Firmware del nodo de campo para ESP32-S3 con tres radares y su propio panel web
* **[ARMOR-SOLAR](https://github.com/JuanenRac/ARMOR-SOLAR)** - Protocolos de inversores y baterías solares y los mensajes de un nodo pasarela
* **[ARMOR-ELECTRICAL](https://github.com/JuanenRac/ARMOR-ELECTRICAL)** - Nodo eléctrico: contadores, el mensaje de las lecturas de la red y las reglas para maniobrar
* **[ARMOR-HMI](https://github.com/JuanenRac/ARMOR-HMI)** - Panel táctil: el estado del sistema en una pantalla de pared, armar y reconocer alarmas, y el hogar del asistente de voz
* **[ARMOR-NETWORK](https://github.com/JuanenRac/ARMOR-NETWORK)** - La red local: sus dispositivos, internet y lo que cambia
* **[ARMOR-SERVER](https://github.com/JuanenRac/ARMOR-SERVER)** - Coordinador central: telemetría, alarmas, dispositivos, lecturas solares y cámaras
* **[ARMOR-STUDIO](https://github.com/JuanenRac/ARMOR-STUDIO)** - Consola web: cámaras, radar, alarmas, energía solar y el diseñador de sitio 2D/3D
* **[ARMOR-ANDROID-CONTROL](https://github.com/JuanenRac/ARMOR-ANDROID-CONTROL)** - Cliente Android del operador con radar 2D/3D en vivo
* **[ARMOR-SERVER-AI](https://github.com/JuanenRac/ARMOR-SERVER-AI)** - Política de inferencia visual que explica sus decisiones y nunca actúa
* **[ARMOR-VOICE-AI](https://github.com/JuanenRac/ARMOR-VOICE-AI)** - Intenciones de voz sin conexión con una confirmación imposible de falsificar
* **ARMOR-HARDWARE** (este repositorio) - Cajas, electrónica y la matriz de aceptación en banco
* **[ARMOR-DEVOPS](https://github.com/JuanenRac/ARMOR-DEVOPS)** - Despliegue, el banco de pruebas de la CM5, copias de seguridad y TLS
* **[ARMOR-SIMULATOR](https://github.com/JuanenRac/ARMOR-SIMULATOR)** - Simulador de telemetría sin conexión con fallos repetibles
* **[ARMOR-UPDATER](https://github.com/JuanenRac/ARMOR-UPDATER)** - Detecta, instala y actualiza los propios repositorios del ecosistema
* **[ARMOR-DOCS](https://github.com/JuanenRac/ARMOR-DOCS)** - Arquitectura, base de seguridad y la matriz de capacidades

## 📚 Documentación y comunidad

Dónde leer más:

* [Matriz de capacidades: qué está probado y qué no](https://github.com/JuanenRac/ARMOR-DOCS/blob/main/docs/CAPABILITY_MATRIX.md)
* [Catálogo de proyectos: versiones y cómo dependen unos de otros](https://github.com/JuanenRac/ARMOR-DOCS/blob/main/docs/PROJECT_CATALOG.md)
* [Historial de cambios de este repositorio](CHANGELOG.md)
* [Licencia (GPL-3.0-or-later)](LICENSE)
* Preguntas, ideas e informes: electrohobby3d@gmail.com

## 👤 AUTOR

**JuanenRac (Electro Hobby 3D)** · electrohobby3d@gmail.com

## 📜 LICENCIA

GPL-3.0-or-later - véase [LICENSE](LICENSE).

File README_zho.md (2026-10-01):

<p align="center">
  ARMOR-HARDWARE banner
</p>

# 🧱 ARMOR-HARDWARE

<p align="center">
  <a href="README.md">🇺🇸 English</a> |
  <a href="README_spa.md">🇪🇸 Español</a> |
  <a href="README_fra.md">🇫🇷 Français</a> |
  <a href="README_ita.md">🇮🇹 Italiano</a> |
  <a href="README_deu.md">🇩🇪 Deutsch</a> |
  🇨🇳 <b>简体中文</b> |
  <a href="README_jpn.md">🇯🇵 日本語</a>
</p>

### 外壳、电子器件和台架验收矩阵

<p align="center">
  
  
  
  
</p>

---

**诚实性检查 - 今天真正能运行的部分:** 外壳是一个**可打印的机械起点，不是 IP、射频或热学认证。** 没有在原型上测量过任何东西；[台架验收矩阵](docs/BENCH_ACCEPTANCE.md)的每一行都是*未测试*。

---

## 🎯 概述

* **真正的设计是 `CAD/CARCASA_SENSORES.scad`**（附 STL、3MF 和 AMF 导出）：带遮光檐、顶部和底板的 90 度拐角底座、固位台阶、2 mm 滑动前盖和侧翼，全部由命名参数驱动。`scad/node_enclosure.scad` 只是占位盒。
* **预留空间**：三个雷达模块、ESP32-S3-ETH-PoE 开发板、传感器窗口、电缆固定头、PoE 磁性元件和 PTC 加热器。在没有实测衰减的情况下，24 GHz 窗口前不得使用金属、导电或含碳材料。
* **台架验收矩阵：** 射频、环境、电源、网络和摄像头检查，每项都有方法和建议的通过标准，另有待填写的摄像头兼容性表。
* 制造前，记录开发板的精确外形、连接器、螺丝位置、天线禁区、热路径和防护目标（[设计输入](docs/DESIGN_INPUTS.md)）。

## 📂 仓库结构

```text
ARMOR-HARDWARE/
├── CAD/     CARCASA_SENSORES.scad (+ stl, 3mf, amf)
├── scad/    node_enclosure.scad (placeholder)
├── EDA/     KiCad (empty)
└── docs/    DESIGN_INPUTS, VALIDATION, BENCH_ACCEPTANCE
```

## 🛠️ 开发环境

```powershell
openscad -o build/CARCASA_SENSORES.stl CAD/CARCASA_SENSORES.scad
```

参见[验证边界](docs/VALIDATION.md)。预期的硬件许可证是 CERN-OHL-S-2.0；发布设计前请补上其完整文本。

## 🔗 相关项目

**A.R.M.O.R.**（Autonomous Radar & Multimodal Observation Range）是由若干独立仓库组成的周界安防系统。每个仓库都有自己的版本、测试和 README；家族成员如下：

* **[ARMOR-COMMON](https://github.com/JuanenRac/ARMOR-COMMON)** - 消息契约、验证器、一致性向量和生成的类型
* **[ARMOR-RADAR](https://github.com/JuanenRac/ARMOR-RADAR)** - 适用于 ESP32-S3 的现场节点固件，带三个雷达和自带网页面板
* **[ARMOR-SOLAR](https://github.com/JuanenRac/ARMOR-SOLAR)** - 太阳能逆变器与电池的协议，以及网关节点的消息
* **[ARMOR-ELECTRICAL](https://github.com/JuanenRac/ARMOR-ELECTRICAL)** - 电气节点：电表、电网读数消息和开关规则
* **[ARMOR-HMI](https://github.com/JuanenRac/ARMOR-HMI)** - 触摸面板：墙面屏幕上的系统状态、布防与确认，以及语音助手的所在
* **[ARMOR-NETWORK](https://github.com/JuanenRac/ARMOR-NETWORK)** - 本地网络：其设备、互联网以及变化
* **[ARMOR-SERVER](https://github.com/JuanenRac/ARMOR-SERVER)** - 中央协调器：遥测、报警、设备、太阳能读数和摄像头
* **[ARMOR-STUDIO](https://github.com/JuanenRac/ARMOR-STUDIO)** - 网页控制台：摄像头、雷达、报警、太阳能和 2D/3D 场地设计器
* **[ARMOR-ANDROID-CONTROL](https://github.com/JuanenRac/ARMOR-ANDROID-CONTROL)** - 带实时 2D/3D 雷达的 Android 操作员客户端
* **[ARMOR-SERVER-AI](https://github.com/JuanenRac/ARMOR-SERVER-AI)** - 会解释决策且从不执行动作的视觉推理策略
* **[ARMOR-VOICE-AI](https://github.com/JuanenRac/ARMOR-VOICE-AI)** - 带无法伪造确认的离线语音意图
* **ARMOR-HARDWARE** (本仓库) - 外壳、电子器件和台架验收矩阵
* **[ARMOR-DEVOPS](https://github.com/JuanenRac/ARMOR-DEVOPS)** - 部署、CM5 测试台、备份与 TLS
* **[ARMOR-SIMULATOR](https://github.com/JuanenRac/ARMOR-SIMULATOR)** - 带可重复故障的离线遥测模拟器
* **[ARMOR-UPDATER](https://github.com/JuanenRac/ARMOR-UPDATER)** - 发现、安装并更新生态系统自身的仓库
* **[ARMOR-DOCS](https://github.com/JuanenRac/ARMOR-DOCS)** - 架构、安全基线和能力矩阵

## 📚 文档与社区

更多阅读：

* [能力矩阵：哪些已被证实，哪些没有](https://github.com/JuanenRac/ARMOR-DOCS/blob/main/docs/CAPABILITY_MATRIX.md)
* [项目目录：版本以及各仓库之间的依赖](https://github.com/JuanenRac/ARMOR-DOCS/blob/main/docs/PROJECT_CATALOG.md)
* [本仓库的变更记录](CHANGELOG.md)
* [许可证（GPL-3.0-or-later）](LICENSE)
* 问题、想法与反馈：electrohobby3d@gmail.com

## 👤 作者

**JuanenRac (Electro Hobby 3D)** · electrohobby3d@gmail.com

## 📜 许可证

GPL-3.0-or-later - 见 [LICENSE](LICENSE)。

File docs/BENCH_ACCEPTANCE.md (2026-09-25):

# Bench acceptance matrix

Nothing here has been measured yet. Every row starts as **not tested**. The requirements come
from the project specification; the pass criteria marked *proposed* are engineering suggestions
to be confirmed or changed by the owner before a prototype is built, and they are not results.

A row turns to **passed** only with a dated measurement record (instrument, method, value,
photo or log) stored with the prototype. A criterion that cannot be measured is rewritten until it can.

## Radio and sensing

| Item | Requirement | How to verify | Pass criterion | Status |
|---|---|---|---|---|
| 24 GHz transparency of the 1 mm radar cover (printed ASA/PETG) | The cover must not hide a person from the LD2450 | Same target at the same distances with and without the cover; compare reported range and track continuity | *Proposed:* detection range loss under 10 % and no track drops on a walking person at 3 m and 6 m | not tested |
| Cover thickness and distance | The front cover is 2 mm in the CAD, close to a quarter wavelength in an ABS-like plastic; the manual recommends about 3.9 mm or 1 mm or thinner, and 12.4 mm or 18.6 mm from the antenna to the cover | Measure the detection range and position error with covers of about 1 mm, 2 mm and 3.9 mm, and with the antenna at about 12 mm and 18 mm from the cover | *Proposed:* the chosen thickness loses the least range; record the material's real permittivity | not tested |
| Cover material | No metallic, conductive or carbon-loaded material in front of a radar aperture | Material data sheet; repeat the row above for each print material and colour | Attenuation measured for every material actually used | not tested |
| Three-sensor coverage | Three LD2450/LD2461 cover the 90° corner without a blind wedge | Walk a marked arc at 2, 4 and 6 m; record which sensor reports | Every angle covered by at least one sensor; hand-over between sensors keeps one track | not tested |
| Mounting height and back lobe | The manual recommends 1.5 m to 2 m and a metal shield behind the module | Walk behind the enclosure with and without a metal back plate | No phantom tracks from movement behind the node | not tested |
| Sensor separation | Radars do not disturb each other | Run all three, then one at a time; compare tracks | No change in a reference target's reported position beyond sensor noise | not tested |
| Ambient light window | The VEML7700 reads correctly through the translucent window | Compare against a reference lux meter from dark to full sun | *Proposed:* within 20 % across the range; day/night threshold flips at the configured lux | not tested |

## Environment

| Item | Requirement | How to verify | Pass criterion | Status |
|---|---|---|---|---|
| Ingress | Watertight corner enclosure with a peak visor | Spray test to the chosen IP target; cable gland torque per data sheet | *Target to be chosen:* no water inside after the test | not tested |
| Condensation drainage | Drainage holes let condensation out | Cycle temperature and humidity in a chamber or overnight outdoors | No standing water; window stays clear with the heater working | not tested |
| PTC surface temperature | The anti-fog heater must not damage the print or the electronics | Thermocouple on the PTC surface and on the nearest printed wall at full heater duty in a warm enclosure | *Proposed:* printed wall under 60 °C and no deformation after 8 h; well below the material's glass transition | not tested |
| Dew-point control | The heater keeps the window above the dew point | Cold-humid soak; log window temperature and dew point | Window stays more than 3 °C above the dew point while heating; heater off when dry | not tested |
| Print material | ASA or PETG survives the site | Sun and heat soak on a sample | No warp that opens a seam or shifts a sensor | not tested |

## Power and network

| Item | Requirement | How to verify | Pass criterion | Status |
|---|---|---|---|---|
| PoE budget | Node 3.8 to 5.5 W with the heater on; camera about 8 to 12 W; a 30 W PoE+ input leaves about 12.5 W margin | Inline power meter on the 48 V feed at idle, radars on, heater on, camera IR and motor active | Measured peak stays under the 30 W port limit with margin | not tested |
| PoE isolation | The PoE magnetics are isolated | Board and switch data sheets; continuity and hi-pot per the design | Isolation confirmed for the exact board used | not tested |
| Network segmentation | Field devices sit in the sensor VLAN with no internet | From a node and a camera: reach the broker, fail to reach the internet and other VLANs | Only the allowed broker, RTSP and API paths work | not tested |
| Broker identity | One identity and ACL per node | Try to read or write another node's topics with a node's credentials | Refused | not tested |
| Power loss | Central power redundancy | Pull the switch or server power with a UPS in place | Nodes report offline through the last will; the server restarts cleanly | not tested |

## Cameras

| Item | Requirement | How to verify | Pass criterion | Status |
|---|---|---|---|---|
| Stream | RTSP main and sub streams work | Discover paths from the server; view live for an hour | Stable video, no relay restarts | not tested |
| PTZ | Bounded movement over the camera's real protocol (Hi3510, PSIA or ONVIF) | Each direction, zoom and stop from Studio and the phone | Moves and stops; a fixed camera reports a real failure | not tested |
| Digest authentication | The camera accepts the server's authentication scheme | Test each camera model and firmware | Recorded per model in the compatibility table | not tested |

## Compatibility table (fill in per camera)

| Camera model and firmware | RTSP path | Auth | PTZ protocol | Night IR | Result |
|---|---|---|---|---|---|
| | | | | | not tested |

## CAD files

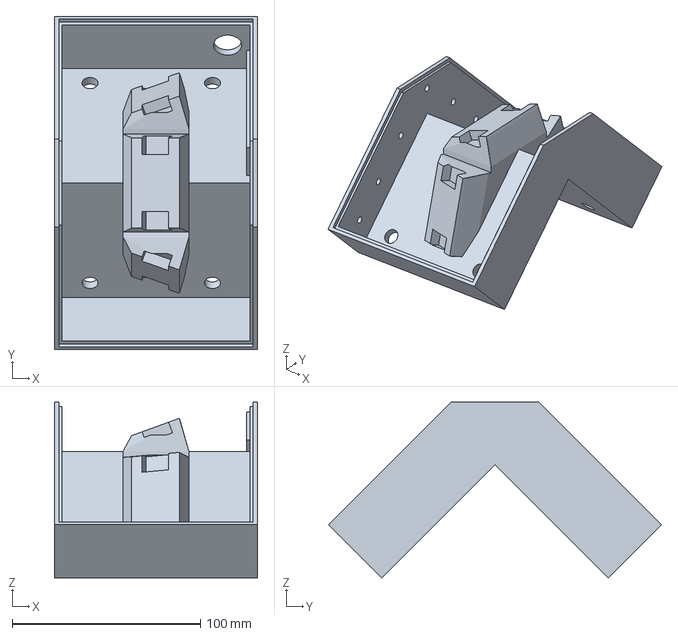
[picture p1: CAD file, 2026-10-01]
scad/node_enclosure_radar_1.3mf
108.0 x 176.8 x 93.3 mm

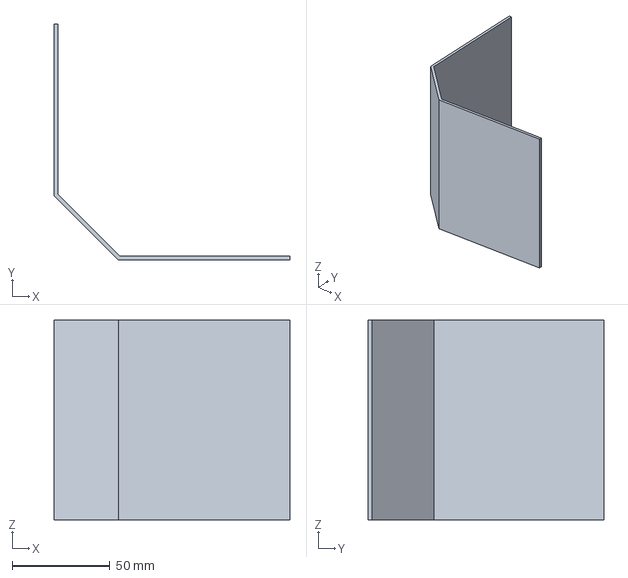
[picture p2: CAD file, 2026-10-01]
scad/node_enclosure_radar_2.3mf
121.0 x 121.0 x 102.5 mm

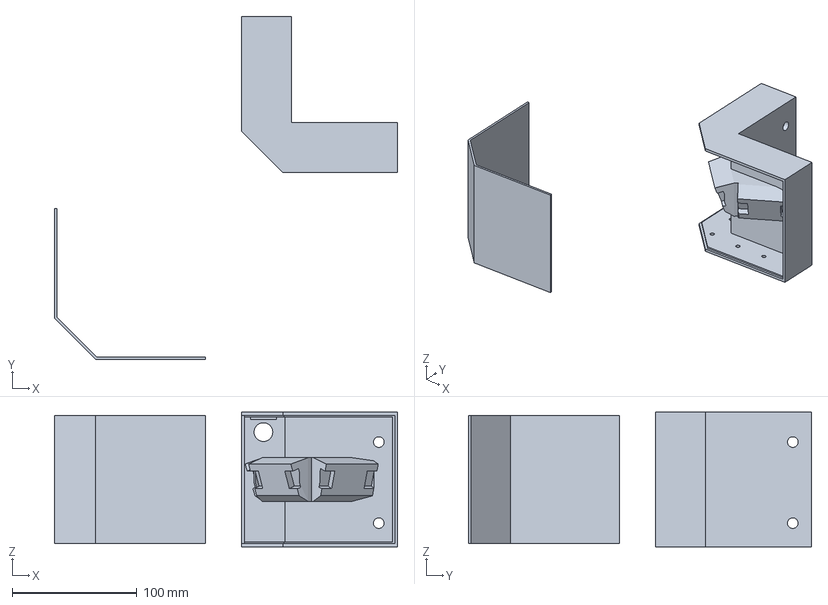
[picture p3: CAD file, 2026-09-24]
scad/node_enclosure_radar.3mf
275.0 x 275.0 x 108.0 mm

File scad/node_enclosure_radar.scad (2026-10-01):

// ==========================================================
// A.R.M.O.R - CORNER BASE WITH DYNAMICALLY LINKED SLOTS
// ==========================================================
$fn = 50;

// ==========================================================
// 1. MAIN BASE STRUCTURE (X, Y, Z)
// ==========================================================
face_length_x = 90;       // Total extension of back wall X (mm)
face_length_y = 90;       // Total extension of back wall Y (mm)
base_height_z  = 100;     // Total height of main base Z (mm)
wall_thickness  = 5;      // Thickness of L-shaped back walls (mm)

// ==========================================================
// 2. FRAME, STEPS, AND COVER PARAMETERS
// ==========================================================

// --- 2.1. CEILING AND FLOOR (Z VISORS) ---
ceiling_z_offset  = 100;  // Z start position of the ceiling (mm)
ceiling_thickness_z  = 4; // Z thickness/depth of the ceiling (mm)

floor_z_offset  = -4;     // Z start position of the floor (mm)
floor_thickness_z  = 4;   // Z thickness/depth of the floor (mm)

// --- 2.2. STEPS / OUTER RETAINING FRAMES (4 SIDES) ---
floor_step_z   = 2.5;     // Bottom tab (floor Z)
ceiling_step_z   = 2.5;   // Top tab (ceiling Z)
lateral_step_x = 0.0;     // Right lateral outer tab (overlap X)
lateral_step_y = 0.0;     // Left lateral outer tab (overlap Y)

// --- 2.3. FRONT COVER (MAIN DIMENSIONS) ---
visor_chamfer  = 33;      // Corner diagonal cut/chamfer size (mm)
cover_thickness     = 2;  // Nominal thickness of the front cover (mm)
cover_clearance_xy = 0.25;// Perimeter sliding clearance in X/Y (mm)
cover_clearance_z  = 0.25;// Vertical clearance in Z (mm)

// --- 2.4. AUTOMATICALLY LINKED SLOT CONTROL ---
// Automatically calculated based on cover_thickness + clearance:
slot_depth_x    = cover_thickness + cover_clearance_xy;  
slot_depth_y    = cover_thickness + cover_clearance_xy;  

// Penetration / Bite inside lateral flaps (mm):
slot_bite_x = 2.0;        // Cut rail depth in lateral flap X
slot_bite_y = 2.0;        // Cut rail depth in lateral flap Y

// --- 2.5. LATERAL FLAPS (X, Y) ---
flap_x_thickness  = 4;    // Total thickness of lateral flap X (mm)
flap_x_overhang_y = 35;   // Outer projection/overhang face X (mm)
flap_x_z_start = -4;      // Vertical Z start of flap X (mm)
flap_x_z_height  = 108;   // Total Z height of flap X (mm)

flap_y_thickness  = 4;    // Total thickness of lateral flap Y (mm)
flap_y_overhang_x = 35;   // Outer projection/overhang face Y (mm)
flap_y_z_start = -4;      // Vertical Z start of flap Y (mm)
flap_y_z_height  = 108;   // Total Z height of flap Y (mm)

separation_distance = 150;// Disassembly distance in view mode 0 (mm)

// ==========================================================
// 3. ELEMENT CONFIGURATION AND DRILL HOLES
// ==========================================================

// --- 3.1. WALL ANCHOR DRILL HOLES (M8) ---
screw_d = 8.5;

wallX_hole_1 = [75, -20, 15];
wallX_hole_2 = [75, -20, 80];
wallY_hole_1 = [-20, 75, 15];
wallY_hole_2 = [-20, 75, 80];

// --- 3.2. LATERAL CABLE GLAND / PASSTHROUGH ---
cable_gland_d = 15;
cable_gland_pos = [-17.5, 88, 88];
cable_gland_rot = [90, 0, 0];

// --- 3.3. TOP LEFT SOLID RECTANGLE ---
rect_length = 73;
rect_width = 21;
rect_thickness = 4;
rect_pos = [-17.5, 35, 100];
rect_rot = [0, 0, 0];

// --- 3.4. CONDENSATION DRAINAGE ---
drain_d = 4;
drain_points = [
    [20, -15, 0],
    [50, -15, 0],
    [75, -15, 0],
    [-15, 20, 0],
    [-15, 50, 0],
    [-15, 75, 0],
    [-12, -12, 0]
];

// --- 3.5. LATERAL SENSOR RECESSES ---
s1_recess_left_height = 15;  s1_recess_left_width = 10;  s1_recess_left_depth = 5;  s1_recess_left_dist = 20;
s1_recess_right_height = 15; s1_recess_right_width = 10; s1_recess_right_depth = 5; s1_recess_right_dist = 20;

s2_recess_left_height = 15;  s2_recess_left_width = 10;  s2_recess_left_depth = 5;  s2_recess_left_dist = 20;
s2_recess_right_height = 15; s2_recess_right_width = 10; s2_recess_right_depth = 5; s2_recess_right_dist = 20;

s3_recess_left_height = 15;  s3_recess_left_width = 10;  s3_recess_left_depth = 5;  s3_recess_left_dist = 20;
s3_recess_right_height = 15; s3_recess_right_width = 10; s3_recess_right_depth = 5; s3_recess_right_dist = 20;

// ==========================================================
// 4. SENSOR DIMENSIONS AND POSITIONS
// ==========================================================
sensor_width = 40;        
sensor_height = 15;         

s1_x = 45;  s1_y = -5;  s1_z = 50;  s1_azimuth = 30;   s1_tilt = 20;
s2_x = -5;  s2_y = 45;  s2_z = 50;  s2_azimuth = -120; s2_tilt = 20;
s3_x = 0;   s3_y = 0;   s3_z = 50;  s3_azimuth = -45;  s3_tilt = 20;  s3_depth = 28;

// ==========================================================
// CONSTRUCTION MODULES AND 2D/3D PROFILES
// ==========================================================

module solid_block(tilt) {
    hull() {
        translate([0, 4, 0]) 
            cube([sensor_width + 12, 8, sensor_height + 20], center=true);
        translate([0, -12, 0]) 
            rotate([tilt, 0, 0]) 
            cube([sensor_width + 8, 2, sensor_height + 12], center=true);
    }
}

module central_solid_block(tilt, depth) {
    hull() {
        translate([0, depth/2, 0]) 
            cube([sensor_width + 12, depth, sensor_height + 20], center=true);
        translate([0, -12, 0]) 
            rotate([tilt, 0, 0]) 
            cube([sensor_width + 8, 2, sensor_height + 12], center=true);
    }
}

module single_recess(width, depth, height, dist_x, tilt) {
    translate([0, -12, 0])
        rotate([tilt, 0, 0])
            translate([dist_x, -1 + depth/2, 0])
                cube([width, depth + 2, height], center=true);
}

// 2D OUTER CEILING/FLOOR PROFILE
module outer_frame_profile_2d() {
    dimension_x = -flap_x_overhang_y - lateral_step_x;
    dimension_y = -flap_y_overhang_x - lateral_step_y;
    
    polygon(points=[
        [wall_thickness, wall_thickness],
        [face_length_x, wall_thickness],
        [face_length_x, dimension_x],
        [dimension_y + visor_chamfer, dimension_x],
        [dimension_y, dimension_x + visor_chamfer],
        [dimension_y, face_length_y],
        [wall_thickness, face_length_y]
    ]);
}

// 2D COVER HOUSING CHANNEL (HOLLOW LAYER BASED ON COVER THICKNESS + CLEARANCE)
module cover_cut_profile_2d() {
    k_off_x = slot_depth_x * (sqrt(2) - 1);
    k_off_y = slot_depth_y * (sqrt(2) - 1);

    p1_out = [face_length_x - flap_x_thickness + slot_bite_x, -flap_x_overhang_y];
    p2_out = [-flap_y_overhang_x + visor_chamfer, -flap_x_overhang_y];
    p3_out = [-flap_y_overhang_x, -flap_x_overhang_y + visor_chamfer];
    p4_out = [-flap_y_overhang_x, face_length_y - flap_y_thickness + slot_bite_y];

    p4_in  = [-flap_y_overhang_x + slot_depth_y, face_length_y - flap_y_thickness + slot_bite_y];
    p3_in  = [-flap_y_overhang_x + slot_depth_y, -flap_x_overhang_y + visor_chamfer + k_off_y];
    p2_in  = [-flap_y_overhang_x + visor_chamfer + k_off_x, -flap_x_overhang_y + slot_depth_x];
    p1_in  = [face_length_x - flap_x_thickness + slot_bite_x, -flap_x_overhang_y + slot_depth_x];

    polygon(points=[p1_out, p2_out, p3_out, p4_out, p4_in, p3_in, p2_in, p1_in]);
}

// 2D FRONT COVER PROFILE (DYNAMICALLY SUPPORTS ANY THICKNESS)
module cover_profile_2d() {
    k_offset = cover_thickness * (sqrt(2) - 1);
    
    p1_out = [face_length_x - flap_x_thickness, -flap_x_overhang_y];
    p2_out = [-flap_y_overhang_x + visor_chamfer, -flap_x_overhang_y];
    p3_out = [-flap_y_overhang_x, -flap_x_overhang_y + visor_chamfer];
    p4_out = [-flap_y_overhang_x, face_length_y - flap_y_thickness];
    
    p4_in  = [-flap_y_overhang_x + cover_thickness, face_length_y - flap_y_thickness];
    p3_in  = [-flap_y_overhang_x + cover_thickness, -flap_x_overhang_y + visor_chamfer + k_offset];
    p2_in  = [-flap_y_overhang_x + visor_chamfer + k_offset, -flap_x_overhang_y + cover_thickness];
    p1_in  = [face_length_x - flap_x_thickness, -flap_x_overhang_y + cover_thickness];
    
    polygon(points=[p1_out, p2_out, p3_out, p4_out, p4_in, p3_in, p2_in, p1_in]);
}

// ==========================================================
// MAIN BASE PIECE
// ==========================================================

module outer_support() {
    dimension_x = -flap_x_overhang_y - lateral_step_x;
    dimension_y = -flap_y_overhang_x - lateral_step_y;

    cut_start_z = floor_z_offset + floor_step_z; 
    cut_end_z    = ceiling_z_offset + ceiling_thickness_z - ceiling_step_z;
    total_cut_h  = cut_end_z - cut_start_z;
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

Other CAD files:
scad/node_enclosure_radar.amf
scad/node_enclosure_radar.stl

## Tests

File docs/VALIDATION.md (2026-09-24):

# Hardware validation boundary

The enclosure model is a printable mechanical starting point, not an IP, RF or
thermal rating. Validate 24 GHz attenuation, condensation drainage, cable glands,
PoE isolation and PTC surface temperature on a real prototype before deployment.

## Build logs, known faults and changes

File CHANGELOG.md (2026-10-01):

# Changelog

All notable changes to this project are documented here.

## [0.2.3] - The enclosure moves to `scad/` as the radar enclosure

- The real design, until now `CAD/CARCASA_SENSORES.scad`, is `scad/node_enclosure_radar.scad`, with its STL, 3MF and AMF exports; its parameters and comments are now in English. The placeholder box `scad/node_enclosure.scad` and the `CAD/` folder are gone.
- Two new 3MF slicer project files, `node_enclosure_radar_1.3mf` (the base, about 125 x 125 x 108 mm) and `node_enclosure_radar_2.3mf` (the sliding cover), each ready to slice on its own. `view_mode` (0 exploded, 1 assembled, 2 the base alone, 3 the cover alone) chooses what the file draws or exports.
- The build/test step, CI's OpenSCAD guard and the manifest follow the new path (`armor_project_tool.py` re-synced from ARMOR-COMMON 0.2.7); the seven READMEs describe the new files and the real file tree (they no longer list the empty `CAD/` and `EDA/` folders, which Git never held).

## [0.2.2]

- A GitHub Actions CI baseline (`.github/workflows/ci.yml`): validates the manifest, the version, CHANGELOG.md's heading, the seven README translations' structure and its own local Markdown links, then runs this project's real build/test through `tools/armor_project_tool.py build-test .` (vendored from ARMOR-COMMON, alongside `tools/armor_ci_validate.py` and `tools/_armor_readme_parity.py`, which do the manifest/docs checking).

## [0.2.1] - What the LD2450 manual asks of the enclosure

- Recorded the manual's supply, range, mounting and cover guidance, and worked out that the 2 mm front cover is close to a quarter wavelength in an ABS-like plastic (not one of the two recommended cases). This is arithmetic, not a measurement; the bench matrix gains rows to measure cover thickness and distance, mounting height and the back lobe.

## [0.2.0]

- Bench acceptance matrix and design-input checklist.
- README describes the real `CARCASA_SENSORES.scad` design and its limits.

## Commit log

2026-09-24 Commit inicial
    [CARCASA_SENSORES.3mf, CARCASA_SENSORES.amf, CARCASA_SENSORES.scad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]
2026-09-25 Decodificador LD2450 desde el manual, Compose ejecutado de verdad con tres correcciones, zona con el sector documentado
2026-09-25 Versiones como cuentakilometros: cada entrega sube el parche (0.1.3 -> 0.1.4), sin saltos de minor; documentacion y contratos alineados
2026-09-27 tools/armor_project_tool.py: ARMOR-SOLAR y ARMOR-ELECTRICAL tenian el mismo run.bat/.sh sin destino seguro que ARMOR-RADAR, pero faltaban en la lista y run crasheaba con 'no run rule registered'; ana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
2026-09-27 Notifica al dashboard central tras cada push a main
    Mismo workflow ya usado en la mayoria de repos HYDRA-UMC/URTC: dispara
    un repository_dispatch a JuanenRac/JuanenRac para refrescar el
    dashboard antes del cron horario. El secreto ECOSYSTEM_DASHBOARD_DISPATCH_TOKEN
    sigue sin configurar (no toca ningun repo hasta que exista), asi que
    esto no cambia nada todavia - solo deja el mismo enganche listo en
    todos los repos por consistencia.
2026-10-01 0.2.3: the enclosure is now scad/node_enclosure_radar.scad
    The real corner-base enclosure moves from CAD/CARCASA_SENSORES.* to
    scad/node_enclosure_radar.* (parameters and comments in English), replacing the
    placeholder box scad/node_enclosure.scad. Adds two 3MF slicer project files,
    one for the base and one for the sliding cover.
    The build/test step, CI's OpenSCAD guard and the manifest follow the new path
    (shared tool re-synced from ARMOR-COMMON 0.2.7), build/ is ignored, and the
    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
    [CARCASA_SENSORES.scad, node_enclosure.scad, node_enclosure_radar.3mf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]
